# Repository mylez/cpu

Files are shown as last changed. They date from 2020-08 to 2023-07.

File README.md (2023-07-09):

#### Miles Smith

# 16-Bit Multiprogram Computer
- Supports kernel and user modes.
- Supports interrupts and exceptions for segmentation violations, timeouts, IO etc (via kernel routine).
- Supports user memory protection through virtual pages (64KB data / 128KB code address space per process).
- Supports preemptive multiprogramming via a hardware timer.

## Instruction Set Architecture (ISA)
##### Total: 57 instructions (57 of 128 opcodes reserved)

### Arithmetic Instructions
##### (16)
    add  rx ry rz           (rx <- ry + rz, status updated)
    sub  rx ry rz           (rx <- ry + rz, status updated)
    and  rx ry rz           (rx <- ry & rz, status updated)
    or   rx ry rz           (rx <- ry | rz, status updated)
    xor  rx ry rz           (rx <- ry ^ rz, status updated)
    sgx  rx ry              (rx <- sigex(ry), status updated)
    shl  rx ry              (rx <- shiftl(ry), status updated)
    shr  rx ry              (rx <- shiftr(ry), status updated)
                (imm values)
    add  rx im rz           (rx <- ry + rz, status updated)
    sub  rx im rz           (rx <- ry + rz, status updated)
    and  rx im rz           (rx <- ry & rz, status updated)
    or   rx im rz           (rx <- ry | rz, status updated)
    xor  rx im rz           (rx <- ry ^ rz, status updated)
    sgx  rx im              (rx <- sigex(ry), status updated)
    shl  rx im              (rx <- shiftl(ry), status updated)
    shr  rx im              (rx <- shiftr(ry), status updated)
     ...  (will vary based on alu implementation) ...

### MMIO Instructions
##### (15)
    l    rx ry rz           (vmem_data[ry + rz] <- rx) *
    li   imm                (r7 <- imm) *
    s    rx ry rz           (rx <- vmem_data[...]) *
    lb   rx ry rz           (vmem_data[...] <- rx, byte) *
    sb   rx ry rz           (rx <- vmem_data[...], byte) *
    ats  rx ry rz           (atomic test and set, vmem, byte) *
    lc   rx ry rz           (rx <- vmem_code[...])
    sc   rx ry rz           (vmem_code[...] <- rx)
    kl   rx ry rz           (kmem_data[...] <- rx)
    ks   rx ry rz           (rx <- kmem_data[...], byte)
    kats rx ry rz           (atomic test and set, kernel mem, byte)
    klb  rx ry rz           (rx <- kmem_data[...], byte)
    ksb  rx ry rz           (kmem_data[...] <- rx)
    klc  rx ry rz           (rx <- kmem_code[...])
    ksc  rx ry rz           (kmem_code[...] <- rx)
    
    * l, s, lb, sb, li, and ats are the only mmio instructions available to user programs
    (ie unprotected). all other MMIO instructions are protected instructions.

### Control Flow Instructions
##### (14)
    beq ry rz               branch if equal (pc <- $ry + rz)
    bne ry rz               branch if not equal
    bng ry rz               branch if negative
    bov ry rz               branch if overflow
    bcy ry rz               branch if carry
    b   ry rz               branch (unconditional)
              (imm values)
    beq im rz               branch if equal (r7 <- im, pc <- im + rz)
    bne im rz               branch if not equal
    bng im rz               branch if negative
    bov im rz               branch if overflow
    bcy im rz               branch if carry
    b   im rz
    cll im                  function call (r7 <- pc, pc <- imm, return via add, l, li, ...etc)
    sys im                  system call via exception (r7 <- return value)
      ... (will vary based on implementation) ...

### Kernel / Special Instructions
##### (12)
    ktime   rx              kernel load timer: timer <- rx
    kuser                   enable user mode
    kcaus   rx              kernel read cause: rx <- cause
    keret   rx              kernel read exception return addr: rx <- eret
    kaddr   rx              kernel read exception virtual address: rx <- exc_addr
    kcont   rx              kernel read context register: rx <- context
    krout   rx              kernel read isr register: rx <- isr
    kbase   rx              load page table base register: ptb <- rx
    kptes   rx ry rz        store page table entry, ptb[ry + rz] <- rx
    kptel   rx ry rz        load page table entry, rx <- ptb[ry + rz]
    statr   rx              read status register: rx <- status **
    statl   rx              load status register: status <- rx **

    ** statr and statl are unprotected. all others on the kernel / special list
    are protected instructions.

## Register Layout
### User Registers
There are 8 registers available to a user program. These are:

    r0 - A constant, hard-wired value of zero.
    r1 - General purpose register 1.
    r2 - General purpose register 2.
    r3 - General purpose register 3.
    r4 - Base pointer.
    r5 - Stack pointer.
    r6 - Program counter.
    r7 - Special register (imm. value / int. return value / return address)

### Kernel / Special Registers
There are 7 registers dedicated to kernel functions and special applications. These are:

    status -  Contains the result of the last ALU operation as NZVF used for conditional 
              branching. User-accessible.
    timer -   Preemption timer. Decremented while in user mode. Once it reaches zero,
              it signals a preemption exception. Protected.
    cause -   Contains information about which interrupt or exception the kernel is 
              servicing. Protected.
    eaddr -   Contains the bad virtual address that triggerred an exception, if 
              applicable. Protected.
    eret -    Contains the value of the PC when the exception/interrupt occurred. Used 
              in context switching. Protected.
    context - Contains the value of the r7 when the exception/interrupt occurred. Used 
              in context switching. Protected.
    isr -     Contains the hardwired address of the global kernel interrupt service routine.
    
### Memory Segmentation

Memory is split across both user/kernel domains as well as data/code domains. The
kernel segments are always addressed using physical addresses, while the user segments
are always addressed using virtual address translation via the MMU. In kernel mode,
the CPU will execute code from the kernel code segment. In user mode, it will execute
from the data segment.

In addition to virtual pages for user processes, processes running in kernel mode may
access the kernel RAM / ROM using physical addresses - ie there is only one kernel
address space. The CPU will begin to execute from this kernel address space on startup,
or when handling an exception.

A benefit of this approach is that it allows for data and code to occupy separate
address spaces. Data is byte-addressed. Code is 16 bit word-addressed (since all
instructions are alligned 2-byte boundaries). This provides a larger code memory (192KB in total).

A drawback of this approach is that kernel processes can not share memory with
user processes, and extra care is required in kernel mode to use the appropriate 
instruction the segment you wish to read to or write from.

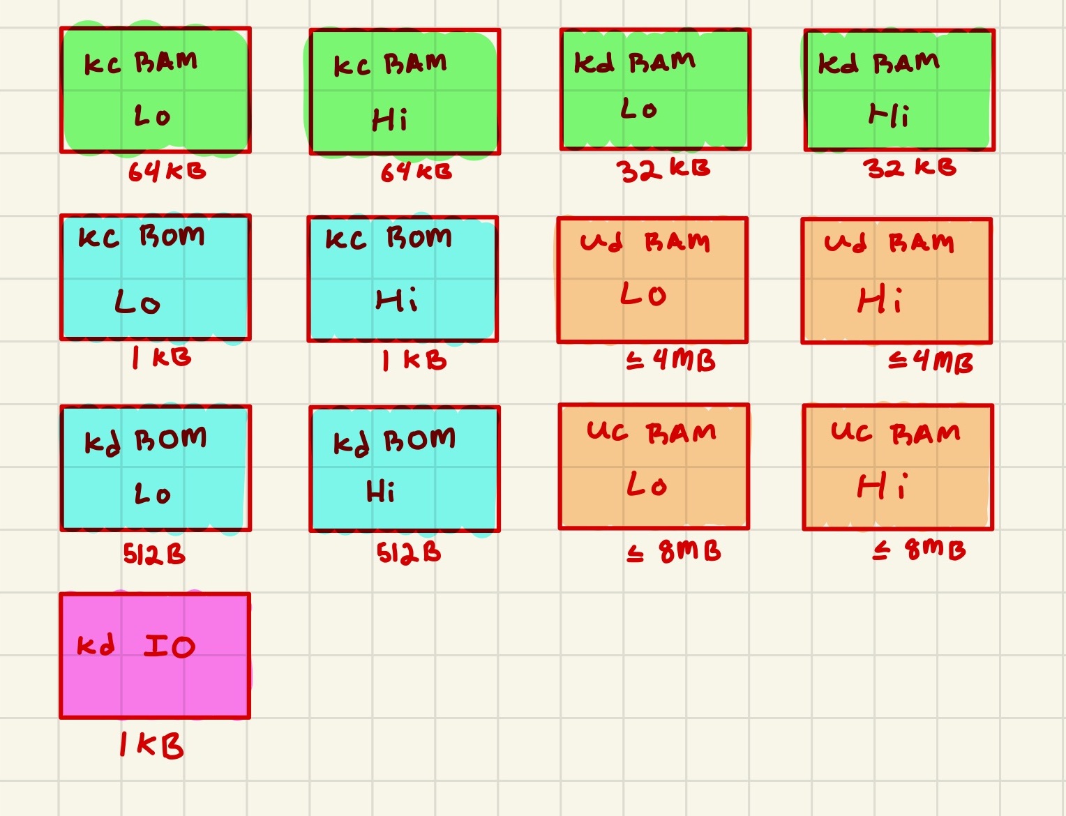
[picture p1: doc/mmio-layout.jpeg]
mmio layout


## Logisim Schematics
#### CPU Main Circuit
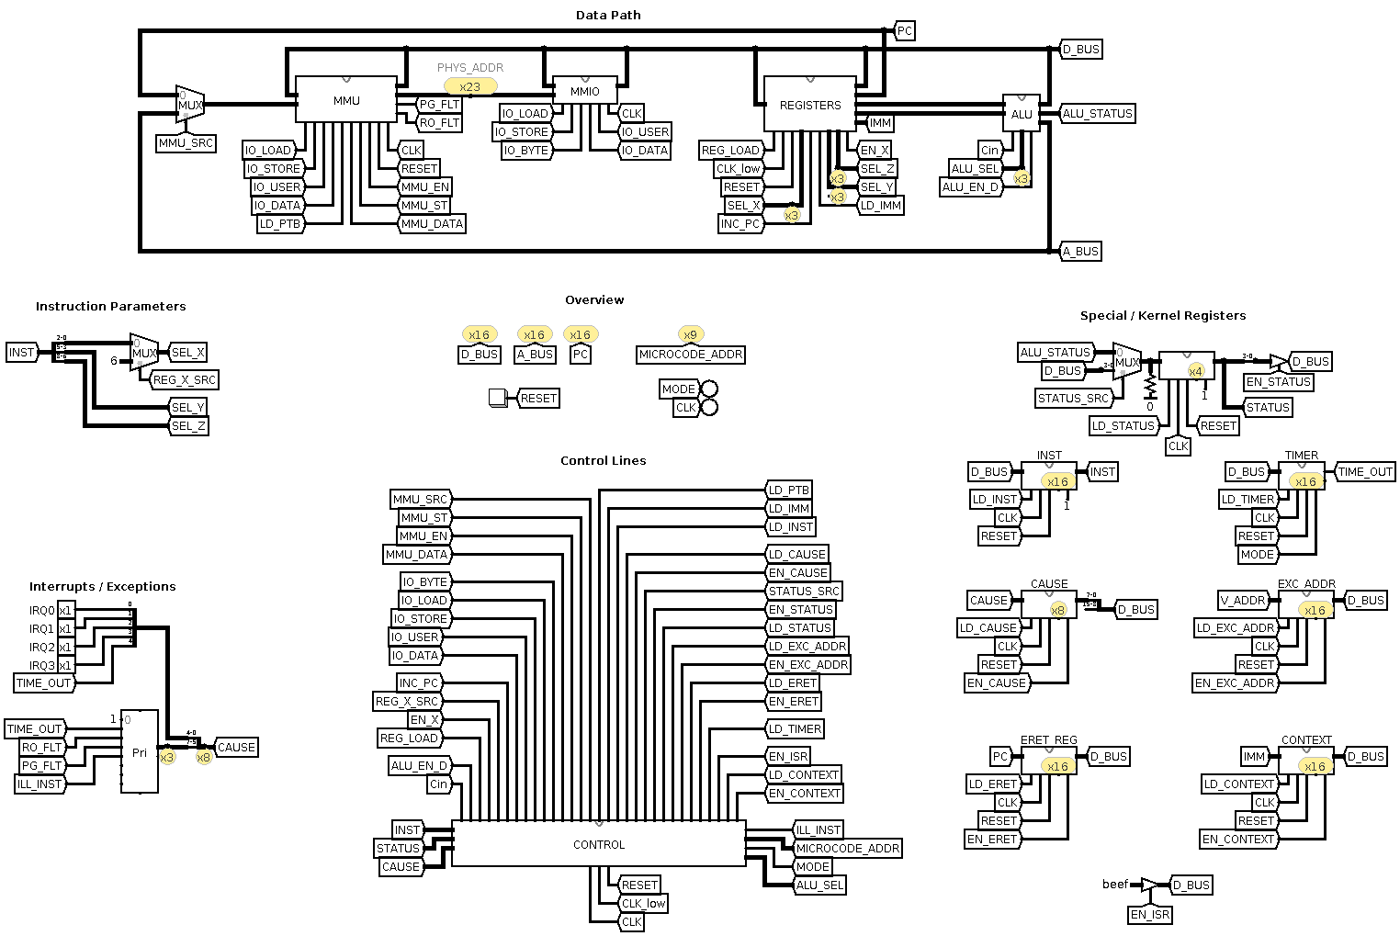
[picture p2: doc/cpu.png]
cpu


#### MMIO Module
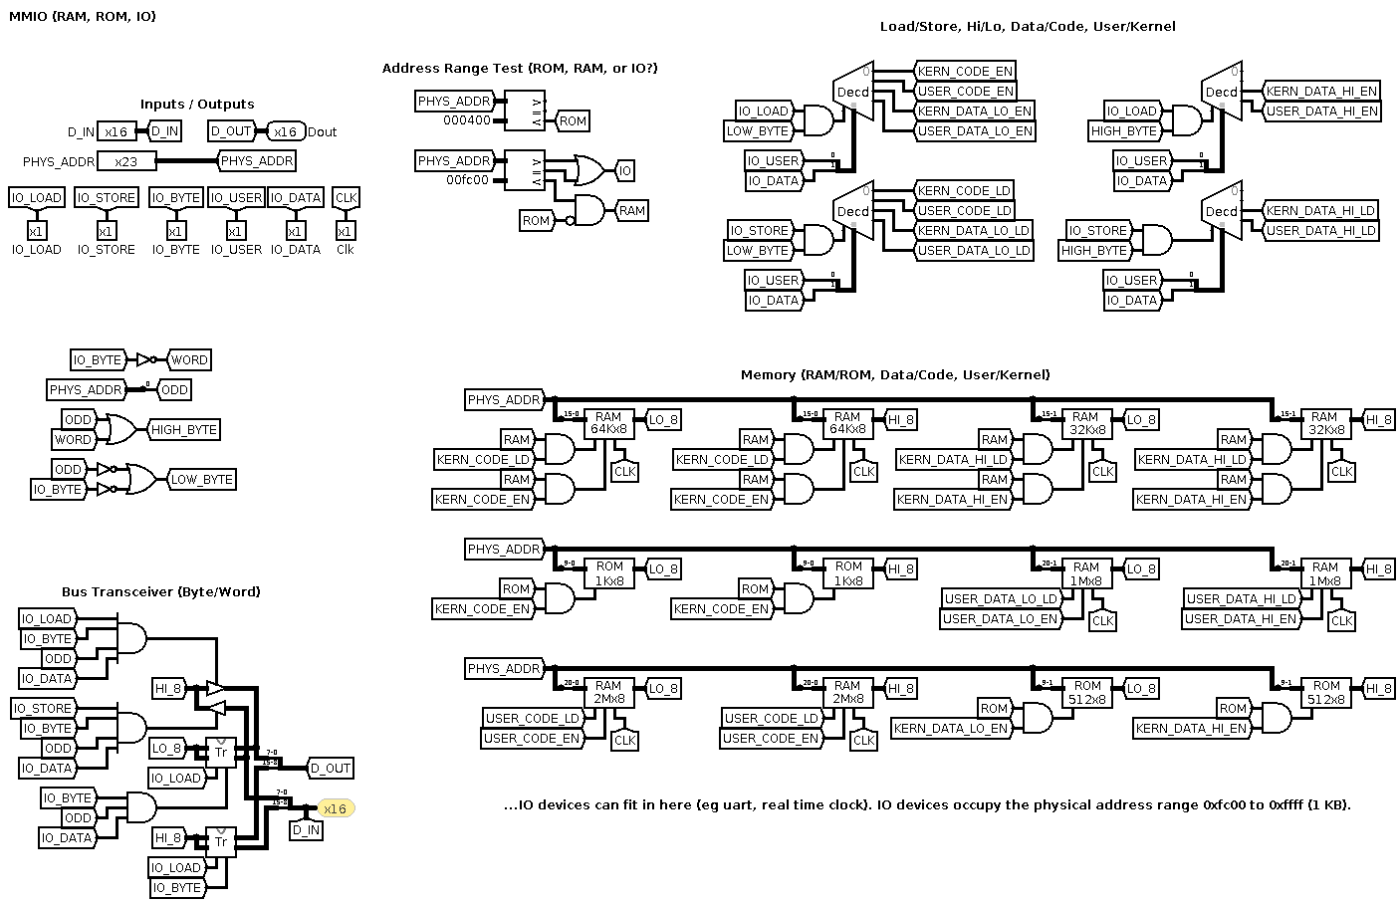
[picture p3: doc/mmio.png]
mmio


#### MMU Module
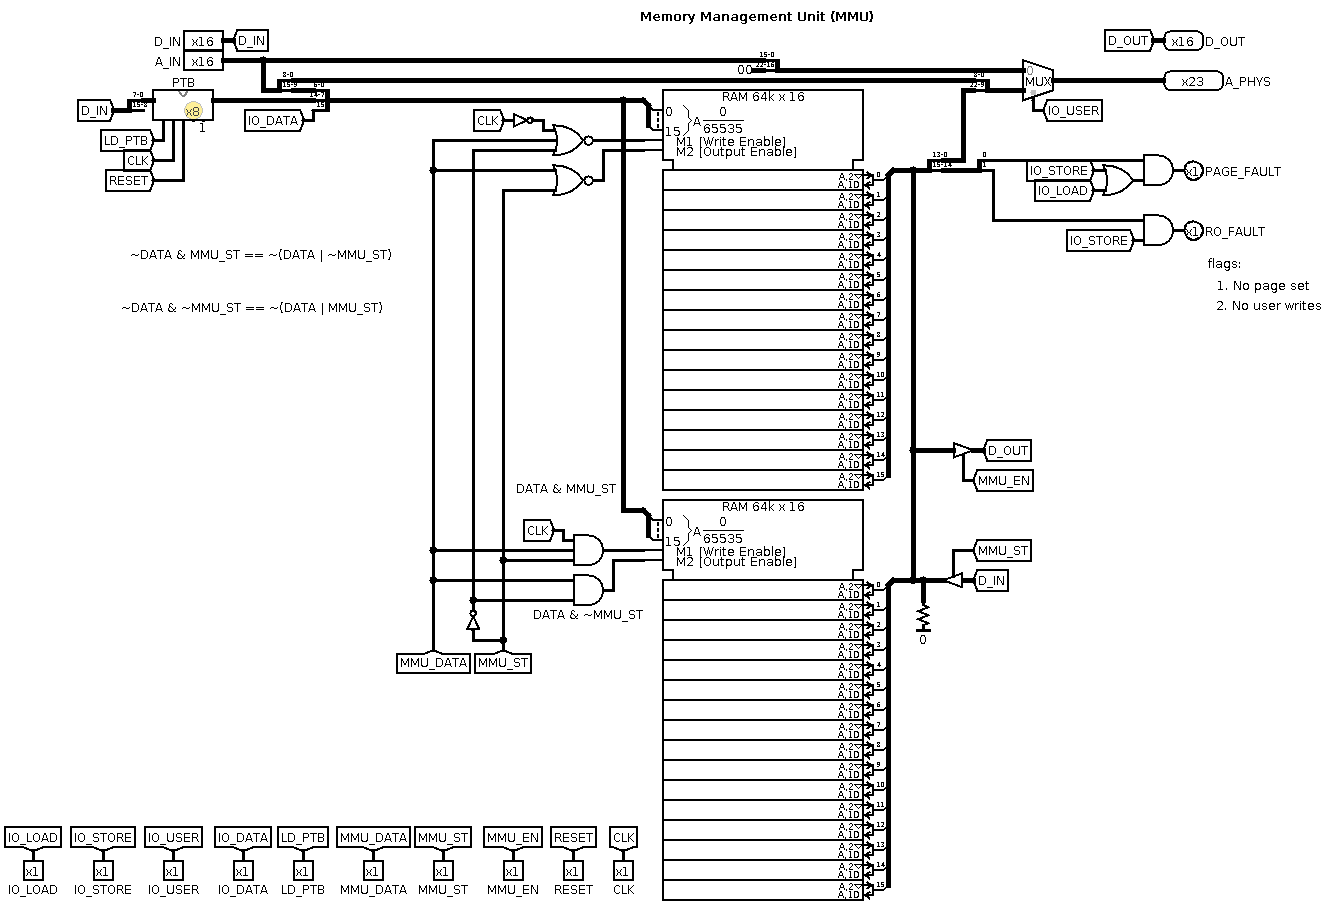
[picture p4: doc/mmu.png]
mmu


#### Control Module
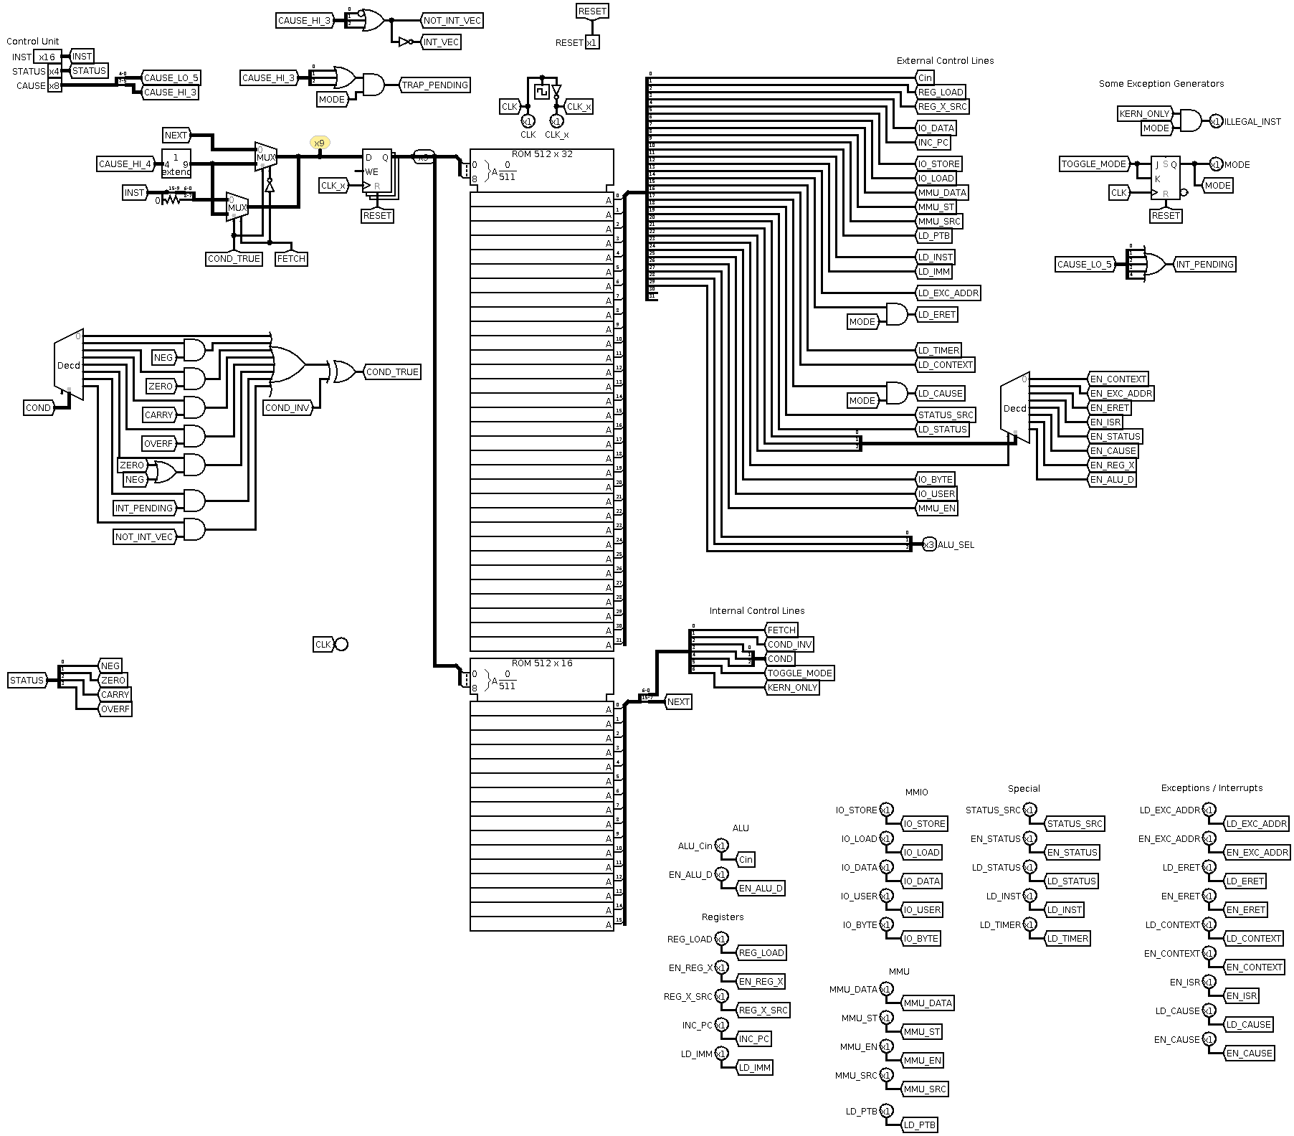
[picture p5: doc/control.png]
control


#### Control State Diagram
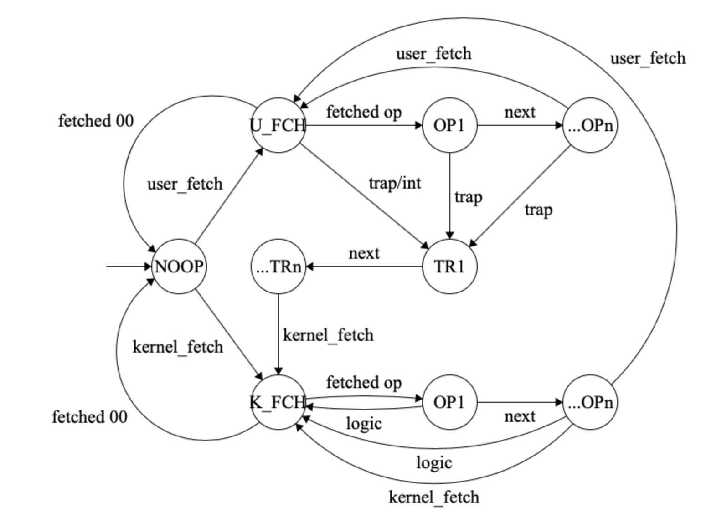
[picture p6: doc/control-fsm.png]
control-fsm


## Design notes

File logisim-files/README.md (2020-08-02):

# logisim files
Logisim circuit files for demonstration and learning purposes

 * `cpu.circ`
    * open in logisim-evolution.jar
    * contains possible layout / datapaths of the cpu to match the instruction format and isa style in isa-2.txt and isa-3.txt
    * in progress (frequent changes)

 * `statemachine.circ`
    * open in logisim-evolution.jar
    * each byte in the ROM stores four bits of its own next address. these form the low four bits of the ROM address.
    * this way, each state of the control unit can define its own next state
    * with more ROM bits and circuitry, this machine could choose between two different next states conditionally
    * if the lowest bit is 1, then it will also update the high 8 bits of the ROM address with the value of OPCODE, effectively moving to the microcode program that defines the instruction represented by OPCODE

 * `register-unit.circ`
    * open in logisim-evolution.jar
    * an example register unit with 3 outgoing buses
    * `X_BUS` is lefthand input to ALU
    * `Y_BUS` is righthand input to ALU
    * `A_BUS` is used to use register value to address memory
    * For a data loading or ALU operation, rX is used as both the lefthand operand of the expression as well as the destination register

 * `simple-datapath.circ`
    * open in default Logisim .jar provided from cburch.com/logisim/download.html
    * contains a very simplified "datapath" with a RAM and three registers
    * one register is used to hold the RAM address
    * any register can be used as input to the ALU stage
    * the ALU stage consists of either ADD (+) or NOT (~)
    * all control signals are manually switched on and off through the use of pins and the poke tool

 * `simple-datapath-with-control.circ`
    * open in default Logisim .jar provided from cburch.com/logisim/download.html
    * contains the sample simplified "datapath" of the previous .circ file, but with automated control lines
    * these control lines are automated through the use of a self-incrementing "control store"
    * this control store is just a 12-bit ROM that stores all of the control lines to perform the desired operation
    * in this case, the rom is loaded with a control sequence that takes the values in RAM at 0x0000 and 0x0001, adds them together, and stores the result in 0x0002
    * in order to see this in action, use the poke tool to place values in 0x0000 and 0x0001 before starting the clock

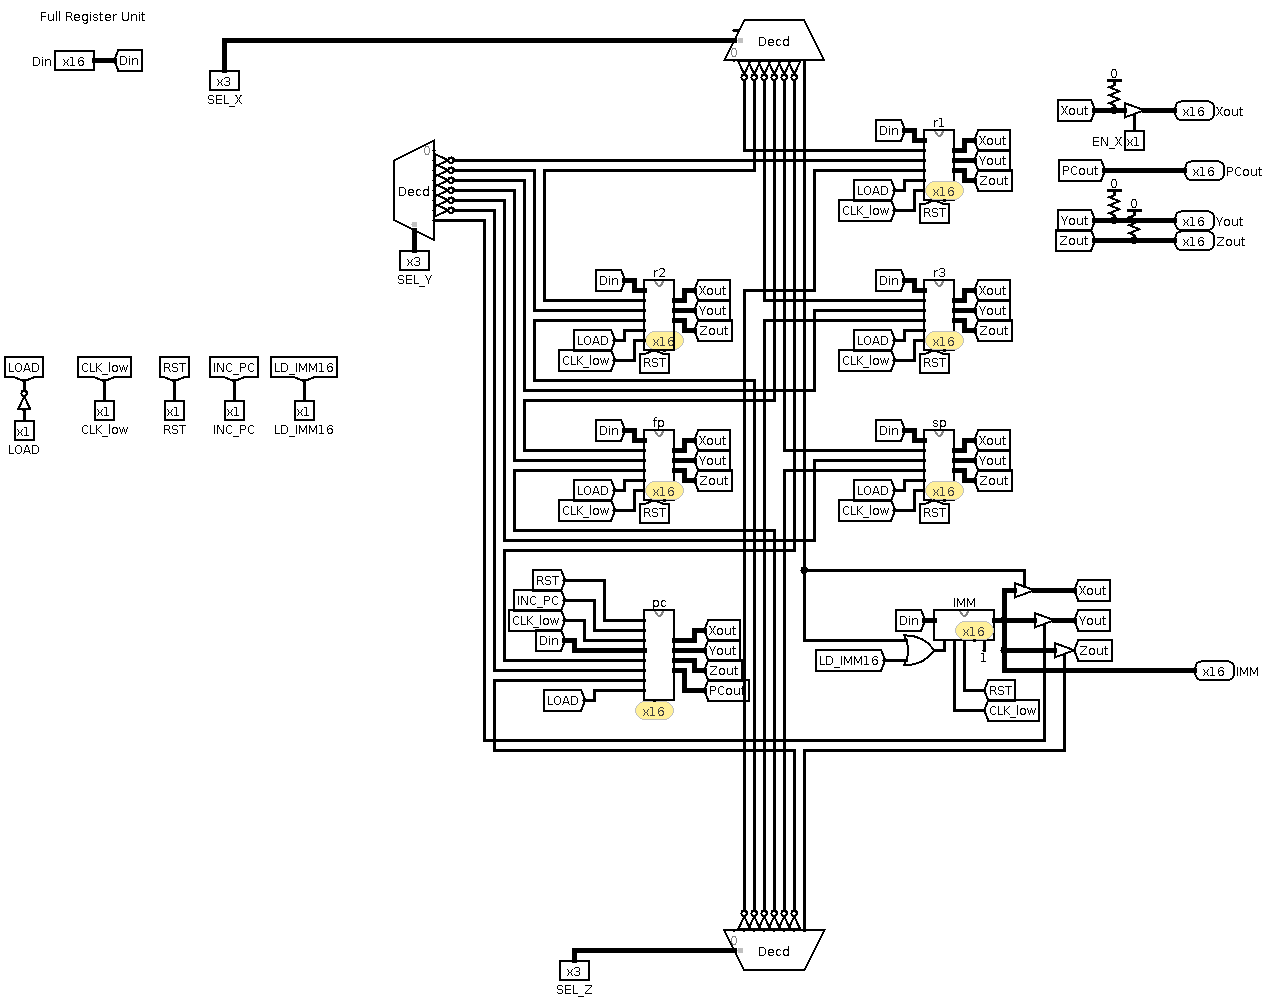
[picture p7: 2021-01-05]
doc/registers.png

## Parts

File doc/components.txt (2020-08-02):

File: components.txt

Author: Miles

Date: June 17, 2019

Description: This file contains a growing list of interesting electronic
components. When some interesting or useful component is encountered, write
about it here.

74x Series Logic ICs
-------------------------------------------------------------------------------
74x381      - 4 bit ALU
74x244      - octal line drivers, 3 state out
74x153      - dual 4 input mux

74x3257     - quad 2 input mux
74x157      - quad 2 input mux

74x273      - octal d flip flop
74x374      - octal d flip flip, 3 state out

74x138      - 1-of-8 decoder / demultiplexer

Serial/IO Interfaces
-------------------------------------------------------------------------------
16550 UART  - UART Serial Interface, used with MAX233
MAX233      - SR232 Driver

Memory
-------------------------------------------------------------------------------
AT28C64B    - (8K x 8) Parallel EEPROM (13 address bits, 8 data bits)
              Electrically erasable & programmable ROM

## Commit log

2020-08-11 add mmio files
    [mmio-unit.kicad_pcb, mmio-unit.sch]
2021-01-15 update photos and circuit
